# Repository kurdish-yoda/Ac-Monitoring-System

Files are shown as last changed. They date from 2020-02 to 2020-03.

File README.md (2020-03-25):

# Ac Monitoring System

Device for monitoring 3 phase AC current. 

## Description
Ability to sample 3 phases at time checking for power losses on individual phases, which should trigger an alert over the GSM 
network. In the event of a complete power out an alarm will be switched on, which will then fasilitate the input of generator volatage.

## Features
- Onion Omega 2+
- SIM800L Module 
- 16 bit ADC
- battery input capabilities
- generator input with surge protection

## Pictures
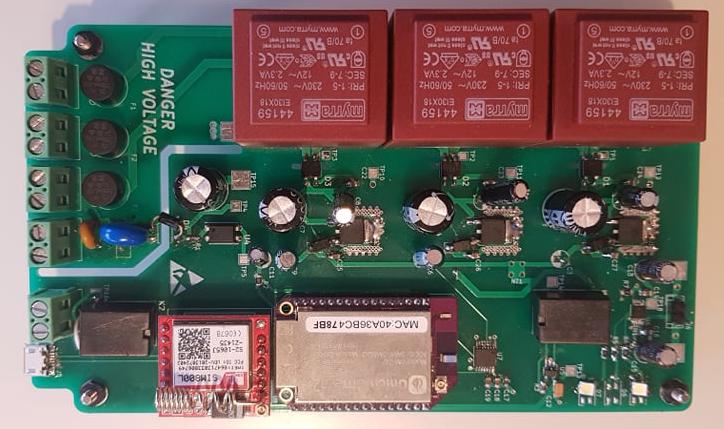
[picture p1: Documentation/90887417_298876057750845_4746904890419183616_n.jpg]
Top view

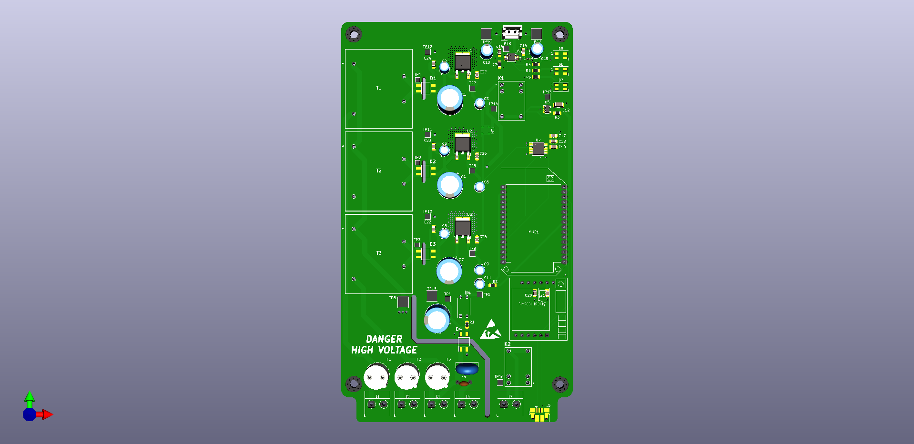
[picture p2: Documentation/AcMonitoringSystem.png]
Top_view


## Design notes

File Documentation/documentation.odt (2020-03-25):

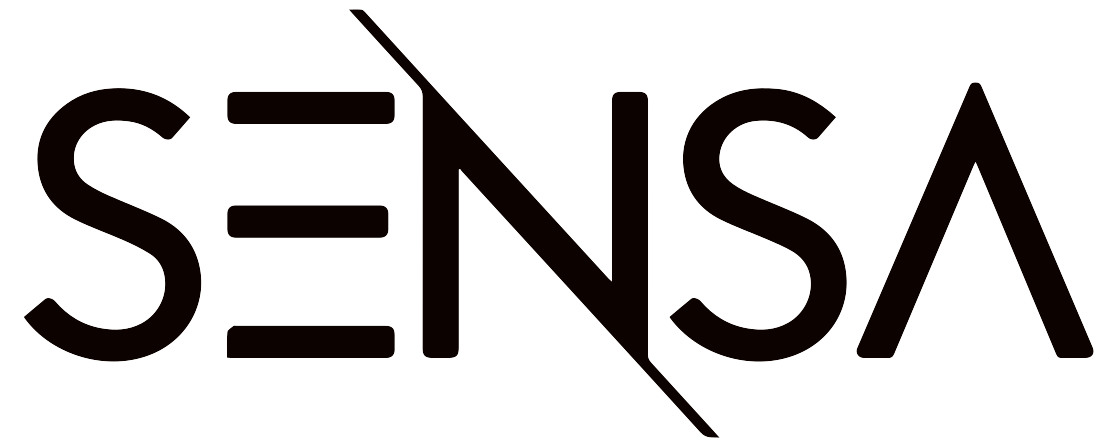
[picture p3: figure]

AC monitoring IOT system


Verzion: | 1.0
Autor: | Ariyan Wasi (ariyan.wasi@sensa-group.net)
| SENSA, 2020

# Hardware history

Ver | Rev | Date | Autor | Description
1 | 1 | 01.03.2020. | Ariyan Wasi | Initial version

# Project Principle

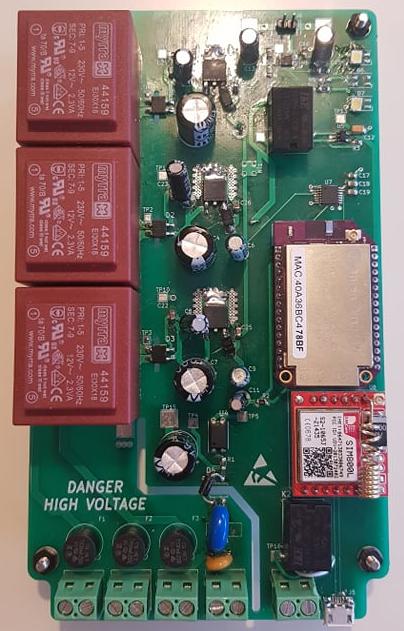
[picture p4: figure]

This system is made to monitor 3 phases of 220 volts and to then to report the data back via GSM or wifi.

In the event of a 1 phase faliure the system will report that back.

In the event of a 3 phase failure the system will short a connection where an alarm or some kind of signaling should be attached.

In the event of a total failure there is an input for a generator with adequte protection.

In the 3 phase failure status, the system will switch to battery power to power the IOT systems to be able to report the failure.

The system also has a micro usb connector for data transfer.

## Workings

Each of the three phases has a fuse, the phase then goes into a transformer that steps the voltage down to around 12V (this most likely will be a bit higher in reality). The 12V then has semi adequate smoothing capacitors atteched. This signal then goes through a linear voltage regulator that takes the signal between 12 and 20 volts and gives a signal of 5V. This 5V signal has its own set of smoothing and decoupling capacitors. (WARN: This should be looked at, as the amount of decoupling seems enough to defirentiate the signals, when looking on the osciloskope however im not sure that the ADC can handle the difierence).

220 VAC

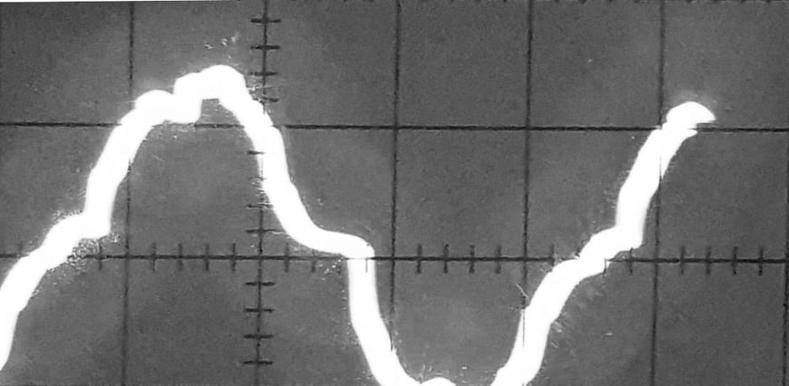
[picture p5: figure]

12 -> 20 VAC

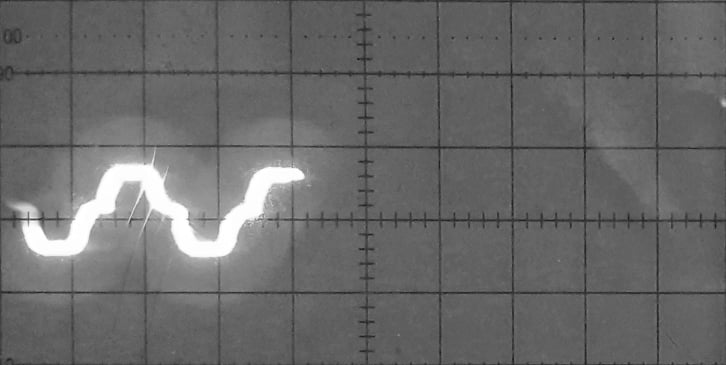
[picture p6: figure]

The 5V signal that went through the L7805 regulator is then used for a multitude of different things. It is firstly connected to the power managment relay. Each of the the three 5 volt signals are routed onto the ADC (MCP3004). In the event of the 3 phase not existing the voltage source will switch to the battery circuit. The signal that is chosen, battery or ac, will then be put into a 3.3 V regulator that will then power the IOT circuitry.

Base line (0V)

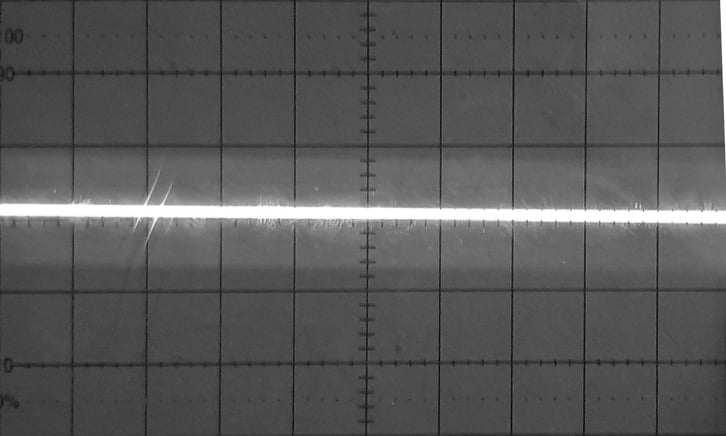
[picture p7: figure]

5 Volts DC

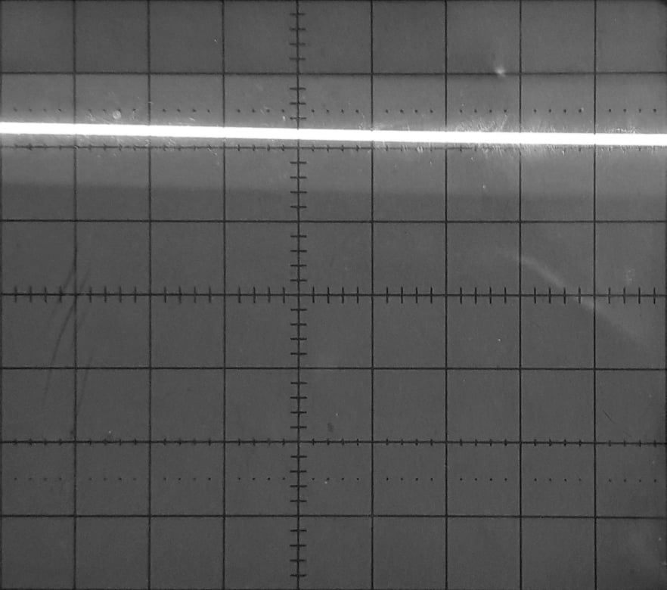
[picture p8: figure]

The generated 3.3 volt signal is either generated through the regulator (MIC5219-3.3YM5) with the AC sourced 5 volt signal or the battery 3.7 volt signal. In either case it generates 3.3 volts. This signal is then used to power the embedded single board computer (onion omega 2 plus) and the GSM module (SIM800L). The signal is also connected to the generator detection circuit via a passthough on the Onion Omega 2 plus.

3.3 Volts DC

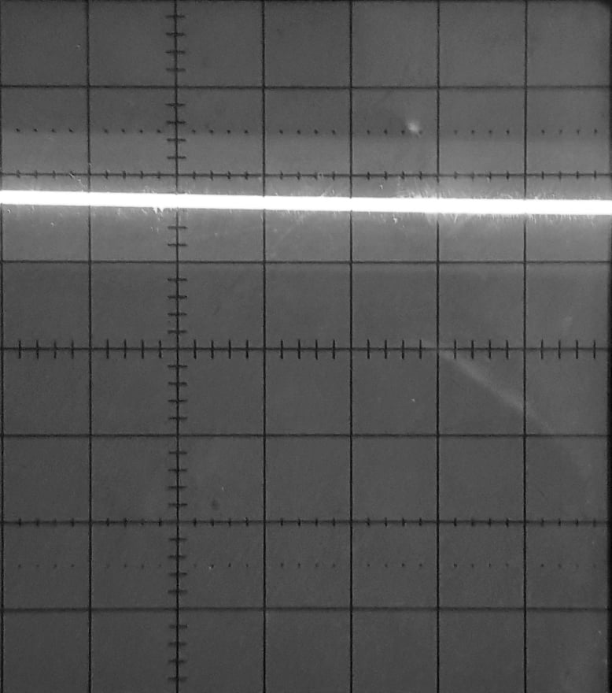
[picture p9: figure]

The system also enables a generator input, this input has a polyfuse and a varisitor attacted as its expected that the genrator will generate significant voltage spikes on power up. This generator voltage is then defaulted to the third AC volatge line to power everytthing and switch the main voltage from battery to AC generated. This voltage does also go through a detection voltage so that the SBC knows where or not its activated. This consists of a rectifier, resistor and optical coupler. that then turns a reference point that is routed to a digital input pin on the SBC. This input also has a smoothing capacitor.

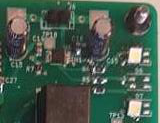
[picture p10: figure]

The battery is manegment is done via the MCP73833-AMI_UN ic. With adequate smoothing and decoupling capacitors, and a 3.7 volt charge indicator. Left side on the conector is ground.

The alarm signalization circuit shorts a lead via a relay in the event that there isnt a 3 phase voltage.

# Visualisation Section

FRONT:

## Front Part

On the front of the PCB we have:

- 3 Phase input

- 3 fuses

- Generator input with protection

- Alarm input with realy attached

- Three 220VAC -> 12VAC transformers

- 3 Rectifiers

- 3 diodes

- Stabilization capacitors

- 3 rectifiers

- More stabilization capacitors

- Power managment relay

- Stabilization capacitors

- Battery input

- Battery managment IC

- Stabilization caps

- Charge Indicators.

- ADC

- stabilization capacitors with tantal

- Onion Omega 2 Plus

- SIM800L

- Optocoupler

- Stabilization capacitor

- Rectifier

- The Whole BOM can be Found At:

https://github.com/kurdish-yoda/Ac-Monitoring-System/blob/master/Documentation/BOM.xls

# Code and Setup

~ TO BE FINISHED BY SOME OTHER PARTY ~

## Setup

Setup the omega acordingly: https://docs.onion.io/omega2-docs/first-time-setup.html

Attache the phases accordingly:

RIGHT --> Neutral (N)

LEFT (TRACE GOES INTO FUSE) --> Live (L)

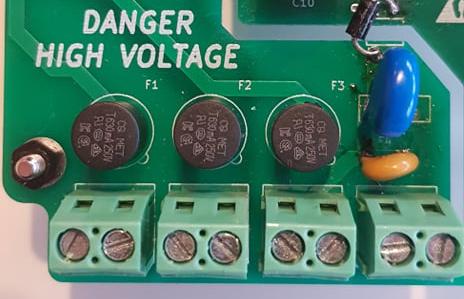
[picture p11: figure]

L N L N L N L(G) N(G)

After this is done the system is ready for development.

# For next version

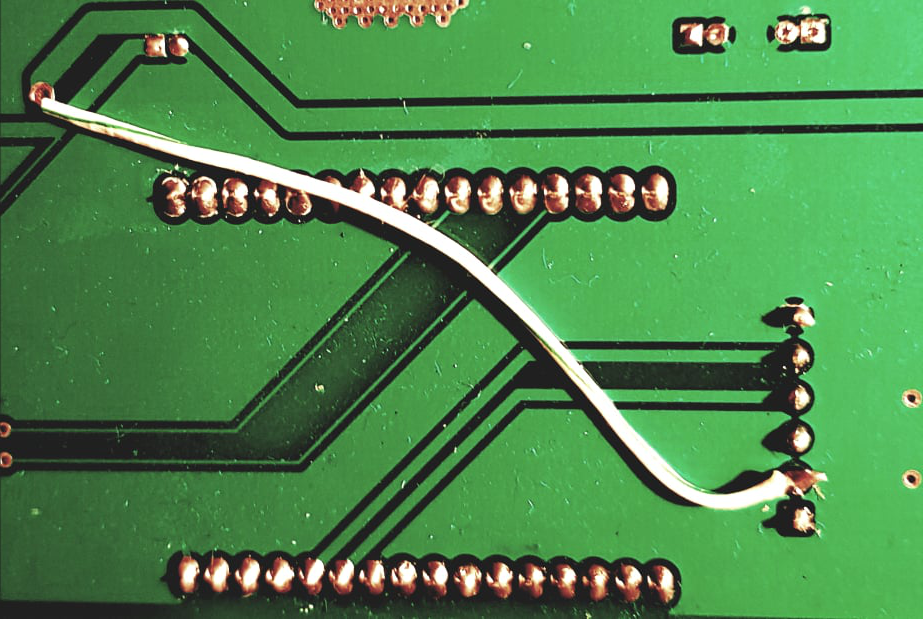
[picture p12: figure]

There are a few things that i say would need to be looked at for a final version or next version. (Most of these will be fixed in the comming week and updated on the github).

1. Fix the missing SIM800L VCC wire (bodge wire on the backside)

2. Relay footprint (manufacturer didnt use standart noticing of viewing angle)

3. Diode footprint (known faulty datasheet entirely)

4. Change MOV footprint

5. Add diodes where needed

6. Power and resitors on usb

7. Redesign power management

8. Add cooling, gets quite hot.

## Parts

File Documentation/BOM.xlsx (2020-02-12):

Line No. | Order Code | RoHS Compliant? | Your Part No | Notes | Qty | Manufacturer Part Number | Manufacturer Name | Manufacturer / Description | Availability | Unit Price | Line Price | Discount Price
1 | 1004398 | RoHS: YES / PHTHALATES: YES | RV1 | MOV | 2 | B72210S0381K101 | EPCOS | EPCOS TVS Varistor, MOV, 385 V, 505 V, StandarD Series, 1.025 kV, Disc 10mm, Metal Oxide Varistor (MOV) | 511 | 0.422 | 0.84
2 | 2752772 | RoHS: YES / PHTHALATES: YES | F4 | PolyFuse | 2 | LVR012S | LITTELFUSE | LITTELFUSE PPTC Resettable Fuse, Through Hole, PolySwitch LVR Series, 120 mA, 300 mA, 240 VAC, -40 °C | 474 | 0.617 | 1.23
3 | 1566069 | RoHS: YES / PHTHALATES: YES | F1, F2, F3 |  | 6 | MCMET 630MA 250V | MULTICOMP PRO | MULTICOMP PRO Fuse, PCB Leaded, 630 mA, 250 VAC, Slow Blow, Radial Leaded | 937149 | 0.0715 | 0.43
4 | 2510249 | RoHS: YES / PHTHALATES: YES | U5 |  | 2 | MIC5216-3.3YM5-TR | MICROCHIP | MICROCHIP Fixed LDO Voltage Regulator, 2.5V to 12V, 300mV Dropout, 3.3Vout, 500mAout, SOT-23-5 | 2392 | 0.96 | 1.92
5 | 1457409 | RoHS: YES / PHTHALATES: YES | C12 |  | 5 | T491A105K025AT | KEMET | KEMET Surface Mount Tantalum Capacitor, 1 µF, 25 V, 1206 [3216 Metric], T491 Series, ± 10%, -55 °C | 20198 | 0.224 | 1.12
6 | 2447662 | RoHS: Y-EX / PHTHALATES: YES | R4, R5, R6 |  | 10 | MCWR08X4700FTL | MULTICOMP PRO | MULTICOMP PRO SMD Chip Resistor, 0805 [2012 Metric], 470 ohm, MCWR Series, 150 V, Thick Film, 125 mW | 57352 | 0.0068 | 0.07
7 | 1649009 | RoHS: YES / PHTHALATES: YES | D5, D6, D7 |  | 10 | LM1-EWN1-11-N2-00001 | CREE | CREE LED, White, SMD, 30 mA, 3.6 V, 1.4 cd | 8389 | 0.166 | 1.66
8 | 2668482 | RoHS: YES / PHTHALATES: YES | J5 |  | 10 | 10118194-0001LF | AMPHENOL ICC | AMPHENOL ICC USB Connector, Micro USB Type B, USB 2.0, Receptacle, 5 Ways, Surface Mount, Right Angle | 27380 | 0.249 | 2.49
9 | 2747640 | RoHS: YES / PHTHALATES: YES | U1, U2, U3 |  | 10 | TS78M05CP ROG | TAIWAN SEMICONDUCTOR | TAIWAN SEMICONDUCTOR LINEAR VOLT REG, 5V, 500MA, TO-252-3 | 4929 | 0.56 | 5.6
10 | 7355572 | RoHS: YES / PHTHALATES: YES | D1, D2, D3, D4 |  | 10 | MBS10 | TAIWAN SEMICONDUCTOR | TAIWAN SEMICONDUCTOR Bridge Rectifier Diode, Miniature, Single Phase, 1 kV, 500 mA, SMD, 1 V, 4 Pins | 1171 | 0.133 | 1.33
11 | 2901332 | RoHS: YES / PHTHALATES: YES | C2, C5, C8 |  | 6 | SS063M0R33B1F-0407 | TEAPO | TEAPO Electrolytic Capacitor, 0.33 µF, 63 V, SS Series, ± 20%, Radial Leaded, 4 mm | 128 | 0.0393 | 0.24
12 | 1870945 | RoHS: YES / PHTHALATES: YES | C3, C6, C9, C11 |  | 8 | MCUMR50V104M4X5 | MULTICOMP PRO | MULTICOMP PRO Electrolytic Capacitor, 0.1 µF, 50 V, MCUMR Series, ± 20%, Radial Leaded, 4 mm | 1455 | 0.0684 | 0.55
13 | 2579786 | RoHS: Y-EX / PHTHALATES: YES | J1, J2, J3, J4, J7 |  | 10 | 20020316-G021B01LF | AMPHENOL ICC | AMPHENOL ICC Wire-To-Board Terminal Block, 5 mm, 2 Ways, 28 AWG, 12 AWG, 2.5 mm², Screw | 410 | 0.268 | 2.68
14 | 1593462 | RoHS: YES / PHTHALATES: YES | U8 | Pins For module | 10 | 2212S-06SG-85 | MULTICOMP | MULTICOMP Board-To-Board Connector, 2.54 mm, 6 Contacts, Receptacle, 2212S Series, Through Hole, 1 Rows | 55168 | 0.119 | 1.19
15 | 1689063 | RoHS: YES / PHTHALATES: TBA | T1, T2, T3 |  | 6 | 44159 | MYRRA | MYRRA Isolation Transformer, EI 30 x 18, 2.3 VA, 12V, 192 mA, 1 x 230V, PCB MOUNTED 44xxx Series | 69 | 3.73 | 22.38
16 | 2456121 | RoHS: YES / PHTHALATES: YES | TH1 | termistor | 10 | NCP15XH103F03RC | MURATA | MURATA Thermistor, NTC, 10 kohm, NCP Series, 3380 K, SMD, 0402 [1005 Metric] | 17110 | 0.0916 | 0.92
17 | 2409048 | RoHS: YES / PHTHALATES: YES | C14, C16, C25, C26, C27, C18, C19, C20 |  | 20 | C0805C105K8RACTU | KEMET | KEMET SMD Multilayer Ceramic Capacitor, 1 µF, 10 V, 0805 [2012 Metric], ± 10%, X7R, C Series KEMET | 9637 | 0.0572 | 1.14
18 | 3013457 | RoHS: YES / PHTHALATES: YES | C24, C23, C22, C17, C21 |  | 10 | CL21A106MQFNNNE | SAMSUNG ELECTRO-MECHANICS | SAMSUNG ELECTRO-MECHANICS SMD Multilayer Ceramic Capacitor, 10 µF, 6.3 V, 0805 [2012 Metric], ± 20%, X5R, CL Series | 25855 | 0.09 | 0.9
19 | 1593463 | RoHS: YES / PHTHALATES: YES | MOD1 | Pins for omega | 10 | 2212S-08SG-85 | MULTICOMP | MULTICOMP Board-To-Board Connector, 2.54 mm, 8 Contacts, Receptacle, 2212S Series, Through Hole, 1 Rows | 53801 | 0.16 | 1.6
20 | 1523365 | RoHS: YES / PHTHALATES: YES | U7 |  | 2 | MCP3004-I/ST | MICROCHIP | MICROCHIP Analogue to Digital Converter, 10 bit, 200 kSPS, Pseudo Differential, Single Ended, Serial, SPI | 186 | 1.73 | 3.46
21 | 1332160 | RoHS: YES / PHTHALATES: YES | U6 |  | 2 | MCP73833-AMI/UN | MICROCHIP | MICROCHIP Battery Charger for 1 Cell of Li-Ion, Li-Pol battery, 6V input, 4.2V / 1A charge, MSOP-10 | 1308 | 0.72 | 1.44
22 | 9451129 | RoHS: YES / PHTHALATES: YES | C10, C7, C4, C1 |  | 8 | MCGPR16V108M10X16 | MULTICOMP PRO | MULTICOMP PRO Electrolytic Capacitor, 1000 µF, 16 V, MCGPR Series, ± 20%, Radial Leaded, 10 mm | 28797 | 0.209 | 1.67
23 | 1236655 | RoHS: YES / PHTHALATES: YES | C13, C15 |  | 5 | MCNP16V105M5X11 | MULTICOMP PRO | MULTICOMP PRO Electrolytic Capacitor, 1 µF, 16 V, MCNP Series, ± 20%, Radial Leaded, 5 mm | 849 | 0.0406 | 0.2
24 | 2447551 | RoHS: Y-EX / PHTHALATES: YES | R3 |  | 10 | MCWR08X1003FTL | MULTICOMP PRO | MULTICOMP PRO SMD Chip Resistor, 0805 [2012 Metric], 100 kohm, MCWR Series, 150 V, Thick Film, 125 mW | 213726 | 0.0067 | 0.07
25 | 9480269 | RoHS: YES / PHTHALATES: YES | K1, K2 |  | 5 | HRS1H-S DC5V | MULTICOMP | MULTICOMP Signal Relay, 5 VDC, SPDT, 3 A, HRS1 Series, Through Hole | 13186 | 1.06 | 5.3
26 | 1738959 | RoHS: Y-EX / PHTHALATES: YES | R2, R7 |  | 10 | CRCW08051K00FKEAHP. | VISHAY | VISHAY SMD Chip Resistor, 0805 [2012 Metric], 1 kohm, CRCW-HP e3 Series, 150 V, Thick Film, 500 mW | 19940 | 0.224 | 2.24
27 | 1244544 | RoHS: YES / PHTHALATES: YES | U4 |  | 5 | HCPL-817-000E | BROADCOM | BROADCOM Optocoupler, Transistor Output, 1 Channel, DIP, 4 Pins, 50 mA, 5 kV, 50 % | 22749 | 0.31 | 1.55
28 | 2426668 | RoHS: Y-EX / PHTHALATES: TBA | R1 |  | 10 | MCHP122WF3603T4E | MULTICOMP PRO | MULTICOMP PRO SMD Chip Resistor, 2512 [6432 Metric], 360 kohm, MCHP12 Series, 250 V, Thick Film, 2 W | 3288 Available until stock is exhausted | 0.0216 | 0.22
29 | 1516289 | RoHS: YES / PHTHALATES: YES | J6 |  | 100 | S2B-XH-A (LF)(SN) | JST (JAPAN SOLDERLESS TERMINALS) | JST (JAPAN SOLDERLESS TERMINALS) Wire-To-Board Connector, Right Angle, 2.5 mm, 2 Contacts, Header, XH Series, Through Hole, 1 Rows | 54943 | 0.095 | 9.5
 |  |  |  |  |  |  | Sub Total | 73.94
 |  |  |  |  |  |  | Goods Total | 73.94
 |  |  |  |  |  |  | Delivery | 0
 |  |  |  |  |  |  | VAT | Unknown
 |  |  |  |  |  |  | Total | 73.94

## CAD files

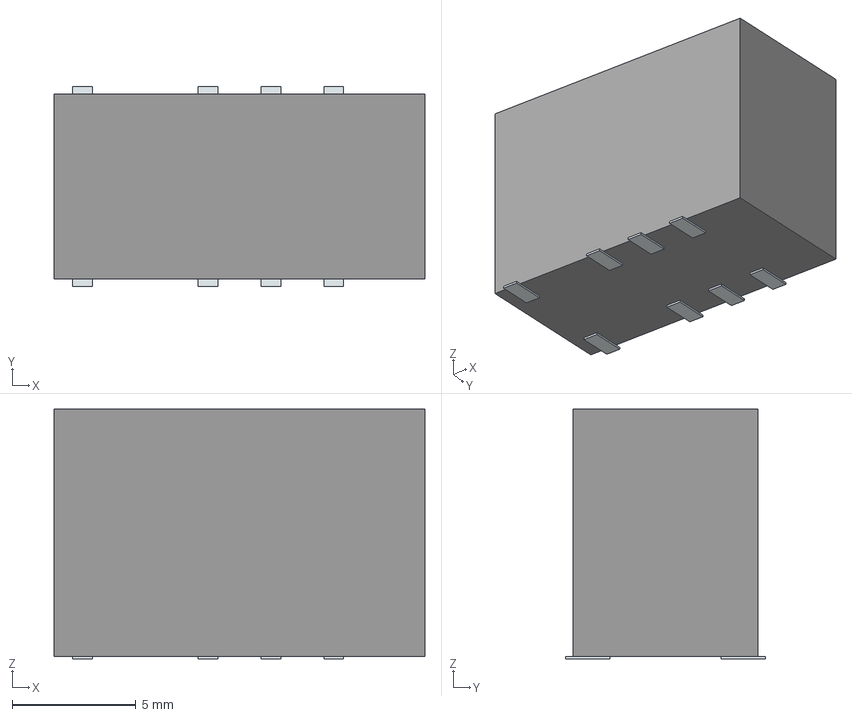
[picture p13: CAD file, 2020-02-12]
PCB/PCB_LIB/LIB_EE2-3NUH-L/EE2-3NUH-L/3D/EE2-3NUH-L.stp
15.0 x 8.09 x 10.1 mm
('pin',_'1')
('pin',_'2')
('pin',_'3')
('pin',_'4')
('pin',_'5')
('pin',_'6')
('pin',_'7')
('pin',_'8')

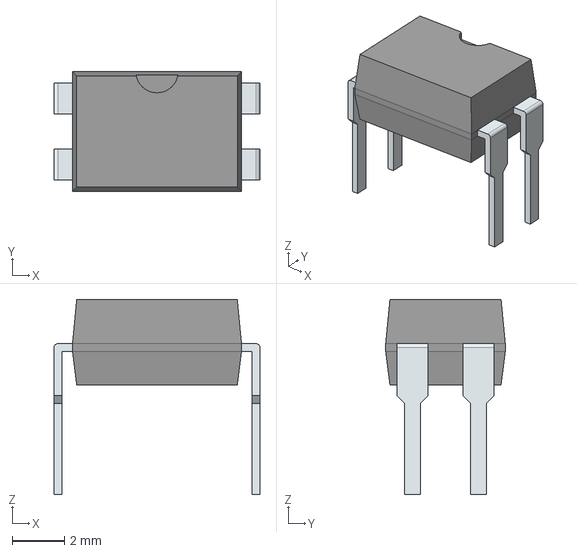
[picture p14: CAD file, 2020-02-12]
PCB/PCB_LIB/LIB_HCPL-817-000E/HCPL-817-000E/3D/HCPL-817-000E.stp
7.92 x 4.60 x 7.50 mm
PinsArrayLR

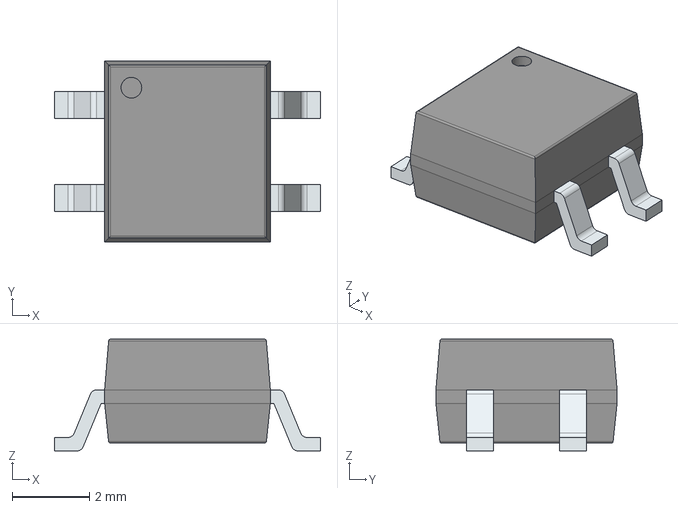
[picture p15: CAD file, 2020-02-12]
PCB/PCB_LIB/LIB_MBS10_RC/MBS10_RC/3D/MBS10_RC.stp
6.90 x 4.70 x 2.90 mm
PinsArrayLR

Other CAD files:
PCB/PCB_LIB/LIB_44159/Allegro/44159.psm
PCB/PCB_LIB/LIB_44159/DEHDL/44159/chips/chips.prt
PCB/PCB_LIB/LIB_EE2-3NUH-L/EE2-3NUH-L/3D/EE2-3NUH-L.stl
PCB/PCB_LIB/LIB_EE2-3NUH-L/EE2-3NUH-L/Allegro/ee23nuhl.psm
PCB/PCB_LIB/LIB_EE2-3NUH-L/EE2-3NUH-L/DEHDL/ee2_3nuh_l/chips/chips.prt
PCB/PCB_LIB/LIB_HCPL-817-000E/HCPL-817-000E/3D/HCPL-817-000E.stl
PCB/PCB_LIB/LIB_HCPL-817-000E/HCPL-817-000E/Allegro/dip762w60p254l460h400q4n.psm
PCB/PCB_LIB/LIB_HCPL-817-000E/HCPL-817-000E/DEHDL/hcpl_817_000e/chips/chips.prt
PCB/PCB_LIB/LIB_HRS1H-S_DC5V/HRS1H-S_DC5V/Allegro/hrs1h-s.psm
PCB/PCB_LIB/LIB_HRS1H-S_DC5V/HRS1H-S_DC5V/DEHDL/hrs1h_s_dc5v/chips/chips.prt
PCB/PCB_LIB/LIB_MBS10_RC/MBS10_RC/3D/MBS10_RC.stl
PCB/PCB_LIB/LIB_MBS10_RC/MBS10_RC/Allegro/sop240p690x290-4n.psm
PCB/PCB_LIB/LIB_MBS10_RC/MBS10_RC/DEHDL/mbs10_rc/chips/chips.prt

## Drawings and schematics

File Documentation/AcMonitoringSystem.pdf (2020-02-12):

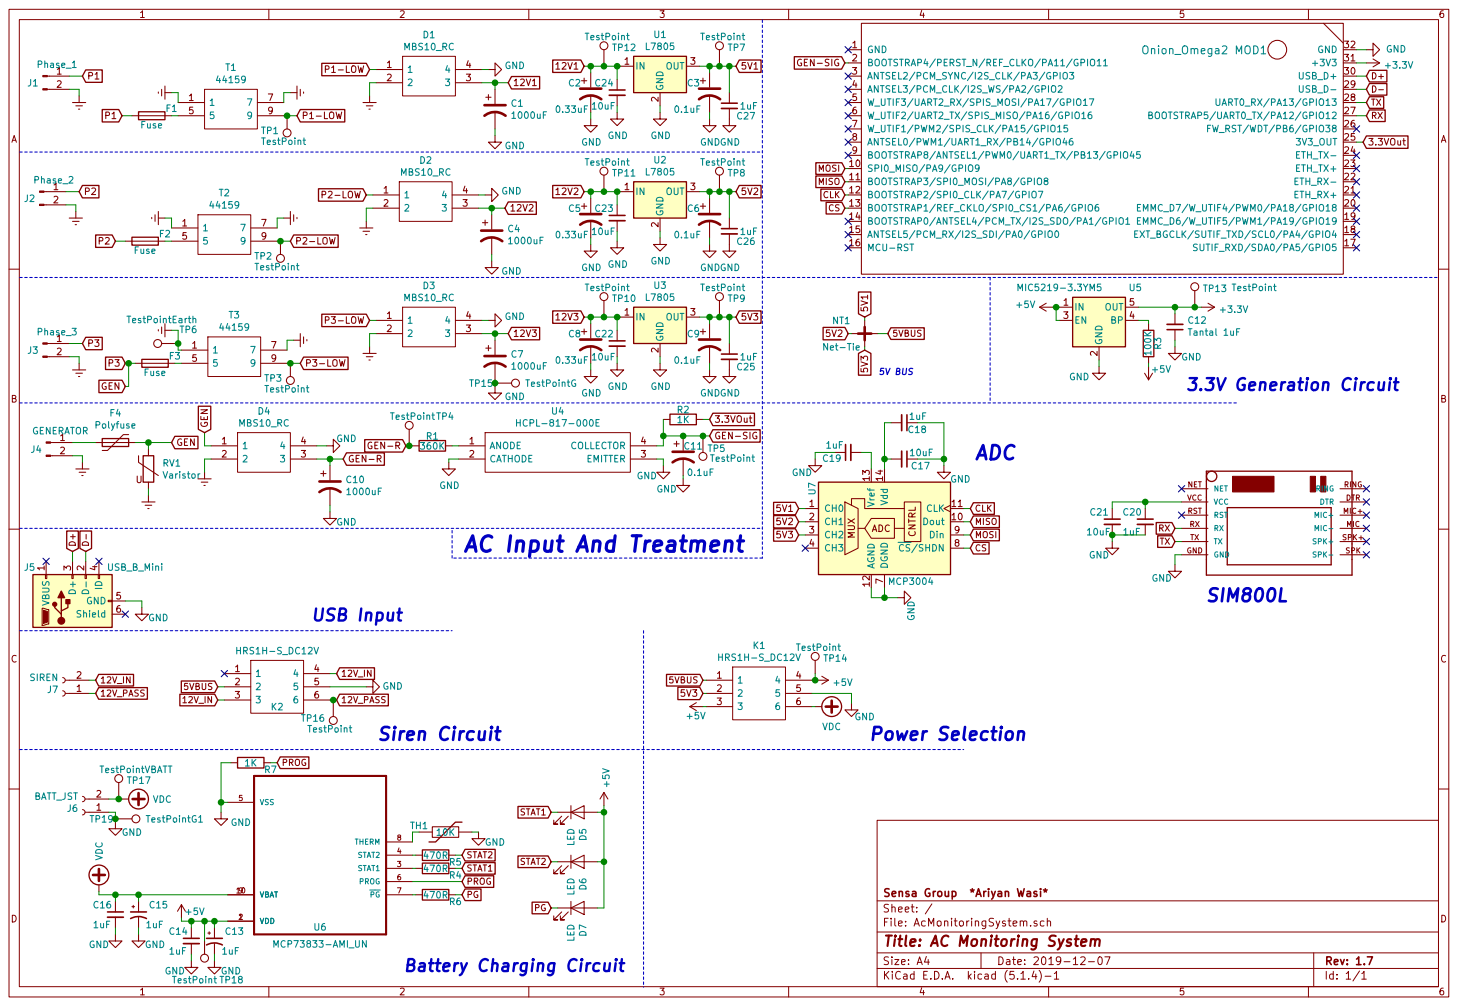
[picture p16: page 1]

2 EN 3 BP 4 OUT 5 MIC5219-3.3YM5 U5 +5V GND R3 100K +5V C12 Tantal 1uF GND

7 CS/SHDN 8 Din 9 U7 MCP3004 GND GND GND

VCC

1uF C21 | RST RST RX RX

SPK+ SPK+ TX TX

Id: 1/1 Title: AC Monitoring System

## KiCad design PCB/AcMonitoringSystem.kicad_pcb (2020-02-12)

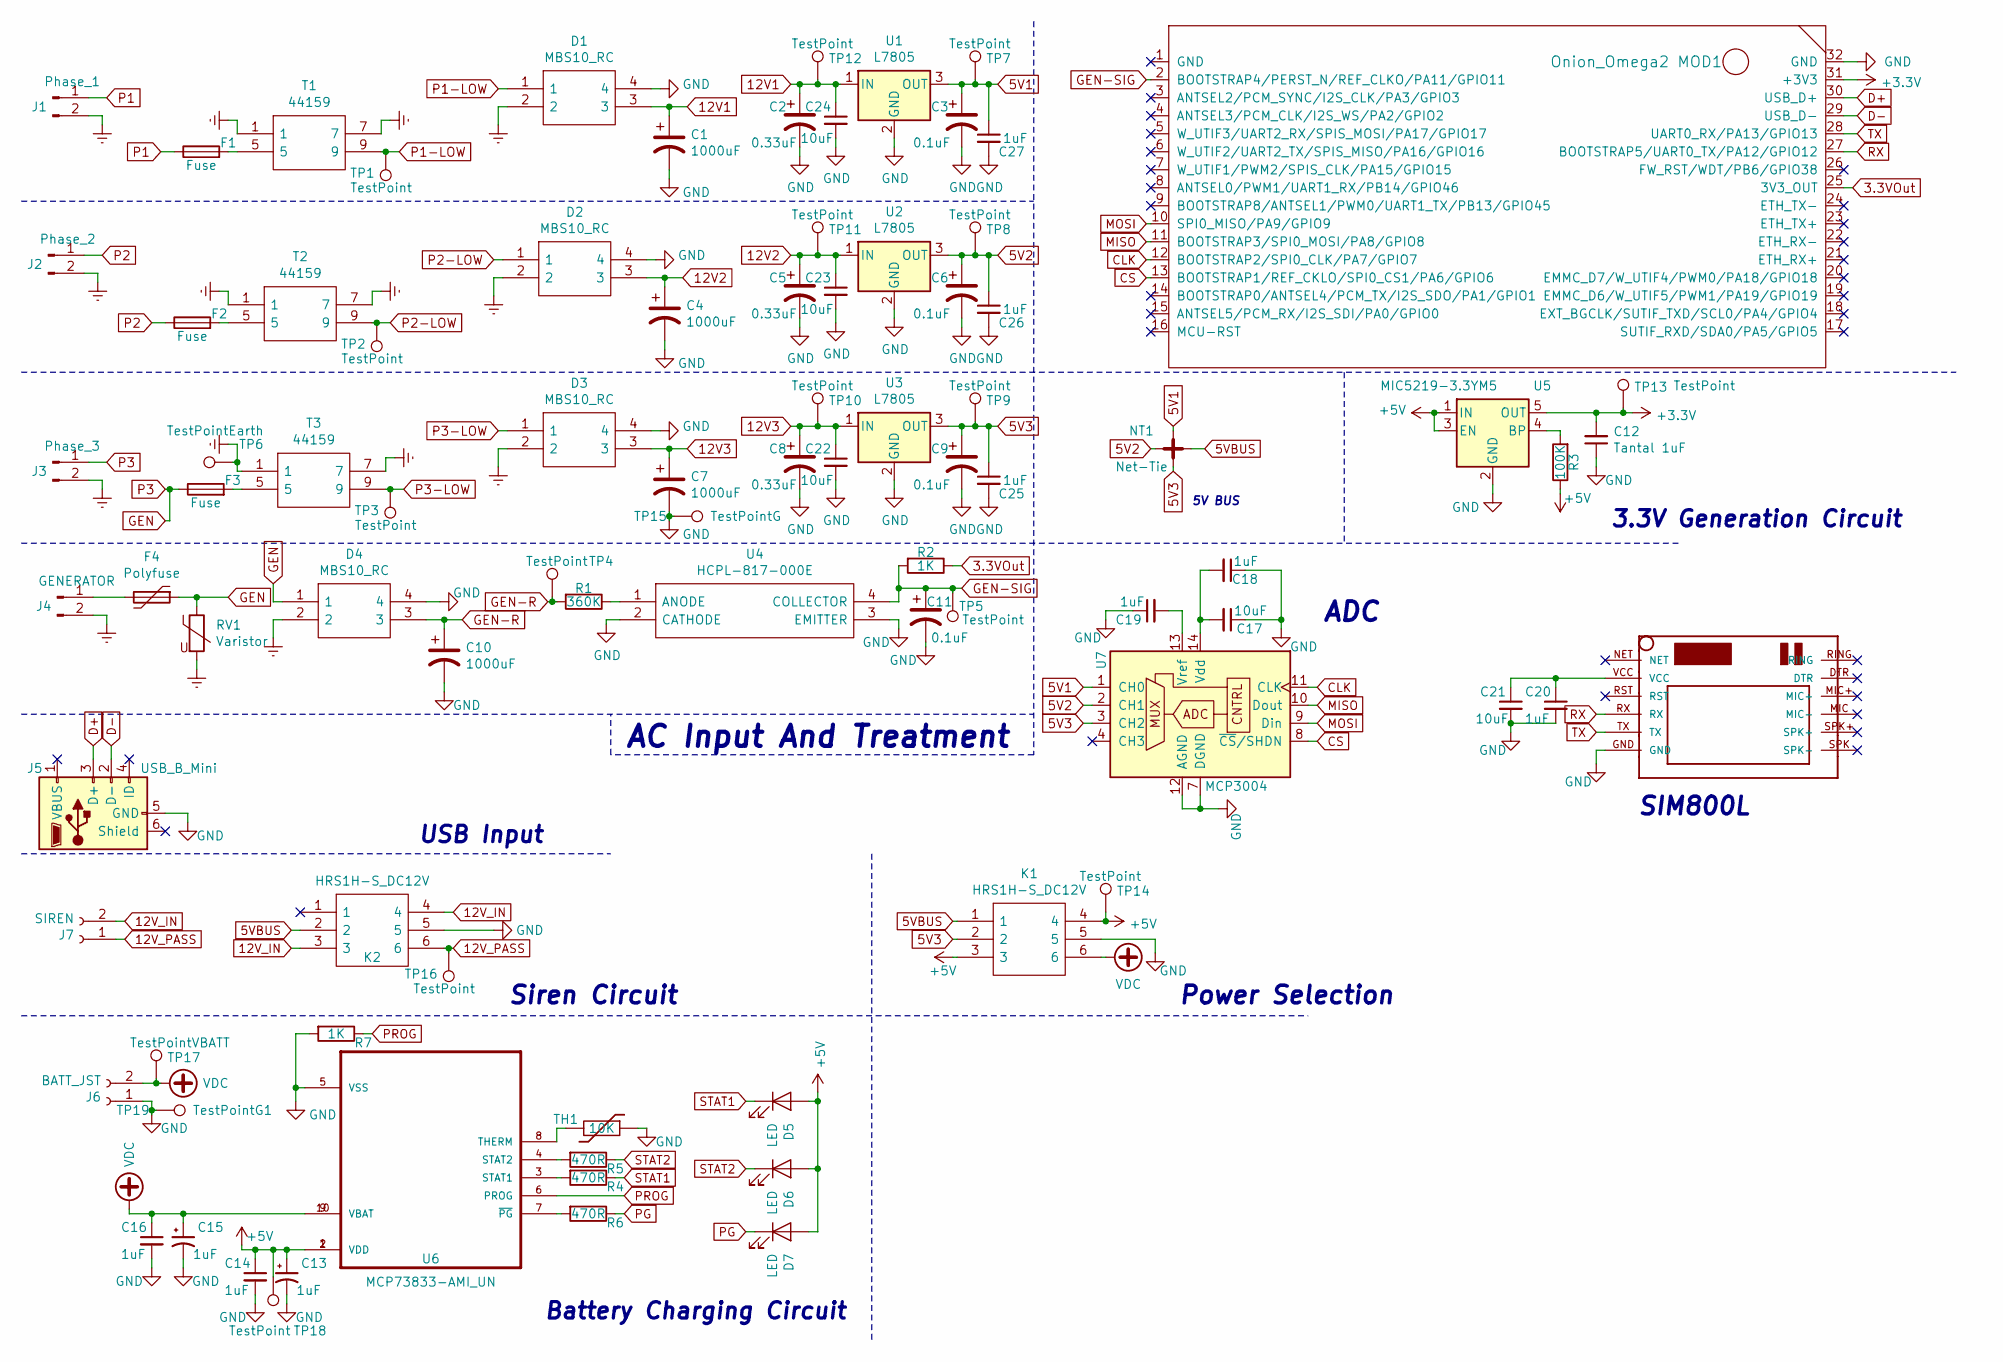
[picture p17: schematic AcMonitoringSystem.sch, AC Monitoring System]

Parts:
C1, C4, C7, C10: 1000uF; CP_Radial_D10.0mm_P5.00mm
C2, C5, C8: 0.33uF; CP_Radial_D4.0mm_P1.50mm
C3, C6, C9, C11: 0.1uF; CP_Radial_D4.0mm_P1.50mm
C12: Tantal 1uF; C_1206_3216Metric_Pad1.42x1.75mm_HandSolder
C13, C15: 1uF; CP_Radial_D5.0mm_P2.00mm
C14, C16, C18, C19, C20, C25, C26, C27: 1uF; C_0805_2012Metric_Pad1.15x1.40mm_HandSolder
C17, C21, C22, C23, C24: 10uF; C_0805_2012Metric_Pad1.15x1.40mm_HandSolder
D1, D2, D3, D4: MBS10_RC; SOP240P690X290-4N; Manufacturer_Part_Number MBS10 RC
D5, D6, D7: LED; LED_SK6812MINI_PLCC4_3.5x3.5mm_P1.75mm
F1, F2, F3: Fuse; Fuseholder_TR5_Littelfuse_No560_No460
F4: Polyfuse; C_Disc_D4.3mm_W1.9mm_P5.00mm
J1: Phase_1; TerminalBlock_Phoenix_MKDS-1,5-2_1x02_P5.00mm_Horizontal
J2: Phase_2; TerminalBlock_Phoenix_MKDS-1,5-2_1x02_P5.00mm_Horizontal
J3: Phase_3; TerminalBlock_Phoenix_MKDS-1,5-2_1x02_P5.00mm_Horizontal
J4: GENERATOR; TerminalBlock_Phoenix_MKDS-1,5-2_1x02_P5.00mm_Horizontal
J5: USB_B_Mini; USB_Micro-B_Wuerth_629105150521_CircularHoles
J6: BATT_JST; JST_EH_B2B-EH-A_1x02_P2.50mm_Vertical
J7: SIREN; TerminalBlock_Phoenix_MKDS-1,5-2_1x02_P5.00mm_Horizontal
K1, K2: HRS1H-S_DC12V; HRS1H-S; Manufacturer_Part_Number HRS1H-S DC5V
MOD1: Onion_Omega2; ONION_OMEGA2
NT1: Net-Tie; NetTie-4_THT_Pad1.0mm
R1: 360K; R_0805_2012Metric_Pad1.15x1.40mm_HandSolder
R2, R7: 1K; R_0805_2012Metric_Pad1.15x1.40mm_HandSolder
R3: 100K; R_0805_2012Metric_Pad1.15x1.40mm_HandSolder
R4, R5, R6: 470R; R_0805_2012Metric_Pad1.15x1.40mm_HandSolder
RV1: Varistor; RV_Disc_D9mm_W3.3mm_P5mm
T1, T2, T3: 44159; Manufacturer_Part_Number 44159
TH1: 10K; R_0402_1005Metric
TP1, TP2, TP3, TP4, TP5, TP7, TP8, TP9, TP10, TP11, TP12, TP13, TP14, TP16, TP18: TestPoint; TestPoint_Pad_2.0x2.0mm
TP6: TestPointEarth; TestPoint_Pad_4.0x4.0mm
TP15: TestPointG; TestPoint_Pad_4.0x4.0mm
TP17: TestPointVBATT; TestPoint_Pad_4.0x4.0mm
TP19: TestPointG1; TestPoint_Pad_4.0x4.0mm
U1, U2, U3: L7805; TO-252-2
U4: HCPL-817-000E; DIP762W60P254L460H400Q4N; Manufacturer_Part_Number HCPL-817-000E; Mouser Part Number 630-HCPL-817-000E
U5: MIC5219-3.3YM5; SOT-23-5
U6: MCP73833-AMI_UN; MSOP-10_3x3mm_P0.5mm
U7: MCP3004; TSSOP-14_4.4x5mm_P0.65mm
U8: SIM800LMODULE

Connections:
3.3VOut: MOD1.25 (3V3_OUT), R2.1
5V1: C3.1, C27.1, NT1.3, TP7.1, U1.3 (OUT), U7.1 (CH0)
5V2: C6.1, C26.1, NT1.1, TP8.1, U2.3 (OUT), U7.2 (CH1)
5V3: C9.1, C25.1, K1.2, NT1.4, TP9.1, U3.3 (OUT), U7.3 (CH2)
5VBUS: K1.1, K2.2, NT1.2
12V1: C1.1, C2.1, C24.1, D1.3, TP12.1, U1.1 (IN)
12V2: C4.1, C5.1, C23.1, D2.3, TP11.1, U2.1 (IN)
12V3: C7.1, C8.1, C22.1, D3.3, TP10.1, U3.1 (IN)
12V_IN: J7.2, K2.3, K2.4
12V_PASS: J7.1, K2.6, TP16.1
+3V3: C12.2, MOD1.31 (+3V3), TP13.1, U5.5 (OUT)
+5V: C13.1, C14.1, D5.2 (A), D6.2 (A), D7.2 (A), K1.3, K1.4, R3.1, TP14.1, TP18.1, U5.1 (IN), U5.3 (EN), U6.1 (VDD), U6.2 (VDD)
CLK: MOD1.12 (BOOTSTRAP2/SPI0_CLK/PA7/GPIO7), U7.11 (CLK)
CS: MOD1.13 (BOOTSTRAP1/REF_CKLO/SPI0_CS1/PA6/GPIO6), U7.8 (~CS~/SHDN)
D+: J5.3 (D+), MOD1.30 (USB_D+)
D-: J5.2 (D-), MOD1.29 (USB_D-)
Earth: D1.2, D2.2, D3.2, D4.2, J1.2, J2.2, J3.2, J4.2, RV1.2, T1.1, T1.7, T2.1, T2.7, T3.1, T3.7, TP6.1
GEN: D4.1, F3.1, F4.1, J3.1, RV1.1
GEN-R: C10.1, D4.3, R1.2, TP4.1
GEN-SIG: C11.1, MOD1.2 (BOOTSTRAP4/PERST_N/REF_CLKO/PA11/GPIO11), R2.2, TP5.1, U4.4 (COLLECTOR)
GND: C1.2, C2.2, C3.2, C4.2, C5.2, C6.2, C7.2, C8.2, C9.2, C10.2, C11.2, C12.1, C13.2, C14.2, C15.2, C16.2, C17.1, C18.1, C19.1, C20.2, C21.2, C22.2, C23.2, C24.2, C25.2, C26.2, C27.2, D1.4, D2.4, D3.4, D4.4, J5.5 (GND), J6.1, K1.5, K2.5, MOD1.32 (GND), R7.2, TH1.1, TP15.1, TP19.1, U1.2 (GND), U2.2 (GND), U3.2 (GND), U4.2 (CATHODE), U4.3 (EMITTER), U5.2 (GND), U6.5 (VSS), U7.7 (DGND), U7.12 (AGND), U8.GND
MISO: MOD1.11 (BOOTSTRAP3/SPI0_MOSI/PA8/GPIO8), U7.10 (Dout)
MOSI: MOD1.10 (SPI0_MISO/PA9/GPIO9), U7.9 (Din)
unnamed: C17.2, C18.2, U7.14 (Vdd)
unnamed: C19.2, U7.13 (Vref)
unnamed: C20.1, C21.1, U8.VCC
unnamed: F1.2, T1.5
unnamed: F2.2, T2.5
unnamed: F3.2, T3.5
unnamed: F4.2, J4.1
unnamed: R1.1, U4.1 (ANODE)
unnamed: R3.2, U5.4 (BP)
unnamed: R4.2, U6.3 (STAT1)
unnamed: R5.2, U6.4 (STAT2)
unnamed: R6.2, U6.7 (~PG~)
unnamed: TH1.2, U6.8 (THERM)
P1: F1.1, J1.1
P1-LOW: D1.1, T1.9, TP1.1
P2: F2.1, J2.1
P2-LOW: D2.1, T2.9, TP2.1
P3-LOW: D3.1, T3.9, TP3.1
PG: D7.1 (K), R6.1
PROG: R7.1, U6.6 (PROG)
RX: MOD1.27 (BOOTSTRAP5/UART0_TX/PA12/GPIO12), U8.RX
STAT1: D5.1 (K), R4.1
STAT2: D6.1 (K), R5.1
TX: MOD1.28 (UART0_RX/PA13/GPIO13), U8.TX
VDC: C15.1, C16.1, J6.2, K1.6, TP17.1, U6.9 (VBAT), U6.10 (VBAT)

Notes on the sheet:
AC Input And Treatment
5V BUS
Battery Charging Circuit
USB Input
3.3V Generation Circuit
Siren Circuit
Power Selection
ADC
SIM800L

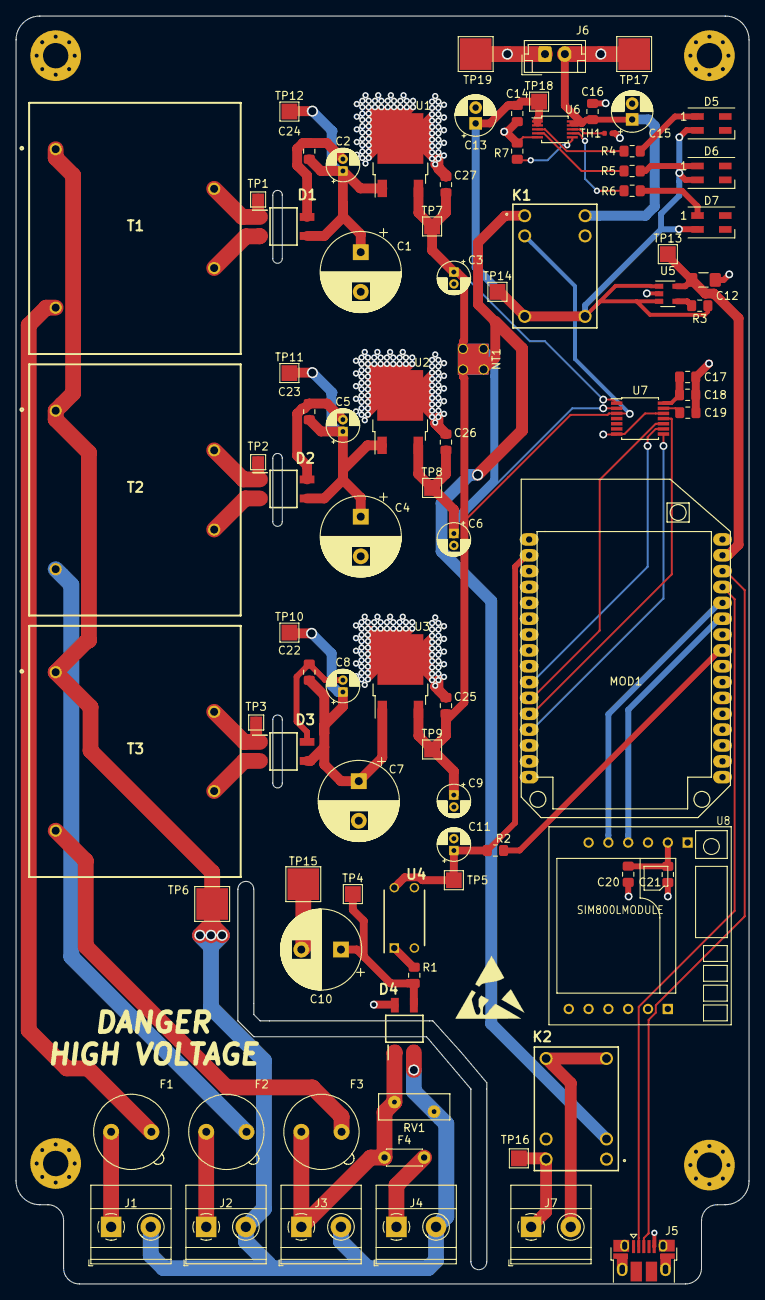
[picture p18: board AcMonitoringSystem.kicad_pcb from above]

Board: 2 copper layers, 92.5 x 160.0 mm, 92 parts (0 on the bottom side), 48 nets.

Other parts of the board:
H1, H2, H4, H4#2: MountingHole; MountingHole_3.2mm_M3_Pad_Via
